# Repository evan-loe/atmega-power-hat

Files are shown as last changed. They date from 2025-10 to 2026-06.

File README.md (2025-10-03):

# ATMEGA Power Hat docs

## Introduction
The *ATMEGA Power Hat* is an RTC enabled Raspberry Pi compatible HAT *(Hardware-Attached-on-Top)* that can automatically wakeup and shutdown the pi on a given schedule.

## Setup Instructions

#### Run `configure_i2c_rtc.sh`
- Run [configure_i2c_rtc.sh](./configure_i2c_rtc.sh) with sudo. This script configures the RTC on the hat as a device recognizable by the Pi as a clock source by adding a dtoverlay. Now, the PI can keep its system time even if it powers off and does not get a chance to sync over NTP.

#### Flash the ATMEGA
- Use the provided .hex files under `build/` to flash the firmware onto the ATEMGA using your ISP and programs such as Microchip Studio or AVRDude. 
- FUSE BITS (Low High Ext): `E2 D9 FF`
- ATMEGA should come shipped with the correct High and Extended fuse bits. Change the low fuse bit to `0xE2` to enable internal clock running at 8 MHz

And thats it! Your hat should be ready to use

## Firmware Description
The source code of the firmware is available in `power.cpp`. It was developed using the Arduino v2.3.6 libararies.

The code does the following when powered ON:
- Sets up the ATMEGA as an I2C receiver on address `0x20`.
- Tells the power controller to send power to the PI by default
- Starts a watchdog that will restart the PIs power if it does not receive communication from the PI

While waiting for successful boot
- **It is the PI's responsibility to tell the ATMEGA of it's successful boot via the `Boot Success` I2C command

After receiving the `Boot Success` signal
- The ATMEGA waits for the `Shutdown` command

When the `Shutdown` command is received
- The ATMEGA waits n seconds as specified by the command. Then, it tells the power chip to cut power. It enters deep sleep mode until the RTC alarm wakes it. Upon awakening, it turns back on the power to the PI, waiting for the `Boot Success` command to be sent from the PI. 

The ATMEGA does not program the RTC over i2c.

## Supported I2C Transactions
The following section describes the transaction format recognized by the ATMEGA. The first byte denotes the command type, and the second byte denotes the value if applicable.

The Base Address of the ATMEGA is `0x20`

| Command | First Byte (txn_type) | Second Byte (data) | Description | Action |
|---|---|---|---|---|
| Shutdown | `0x00` | 0x00-0xFF | Shutdown command | Sets `shutdown_in` variable to data value |
| Boot Success | `0x01` | Any value | Boot success signal | Sets `successful_boot` flag to 1 |

#### Note on max number size
Since any data is encoded in a single byte, the max delay from receiving the i2c signal to cutting power is 2^8=256 seconds.

## Hardware
The CAD files can be found in the [ATMegaPowerCircuit](./ATMegaPowerCircuit/) folder.

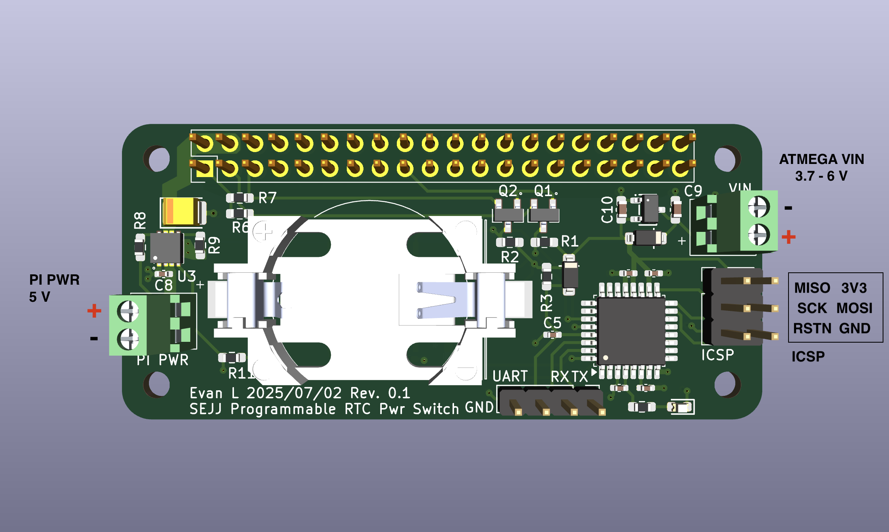
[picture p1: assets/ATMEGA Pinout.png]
ATMEGA Hardware Connections


## Compiling the firmwre
Select the Aruduino UNO as your device. Paste [power.cpp](./power.cpp) into your Arduino IDE and click `Sketch > Export Compiled Binary`

## Additional Reference Information
**RTC lib docs**: https://adafruit.github.io/RTClib/html/index.html (We are using the DS3231 RTC chip)

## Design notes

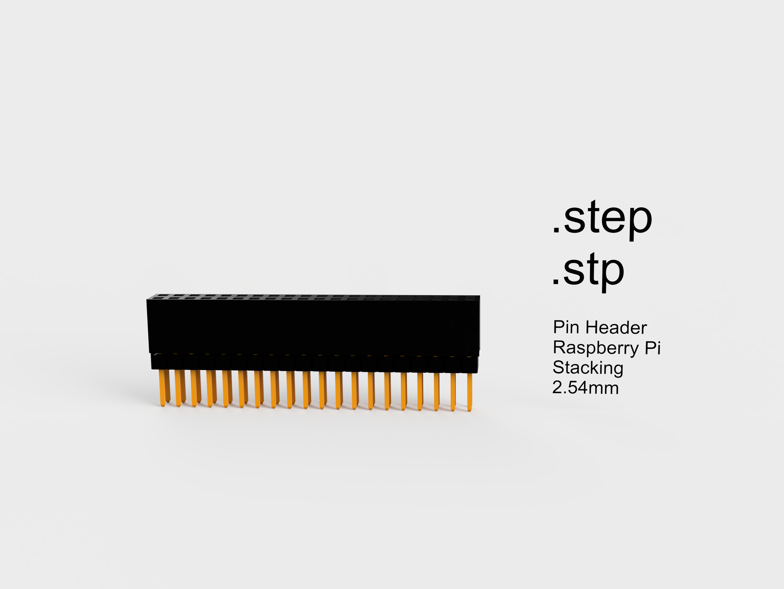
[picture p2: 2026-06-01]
ATMEGA Power Circuit/imported/pin-header-raspberrypi-stacking-2-54mm/Pin_Header-RaspberryPi - Stacking - 2.54mm.png

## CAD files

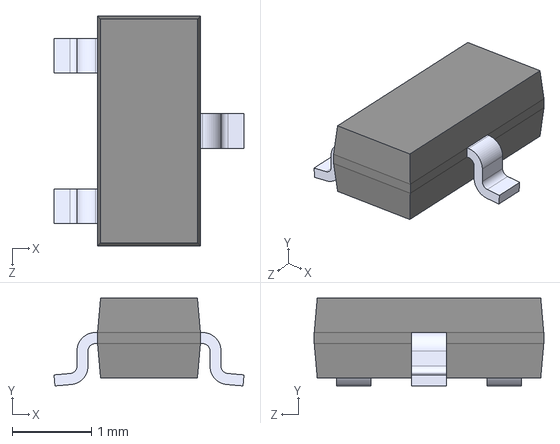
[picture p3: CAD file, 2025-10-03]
ATMEGA Power Circuit/imported/BSS138/BSS138.step
2.40 x 1.11 x 2.90 mm

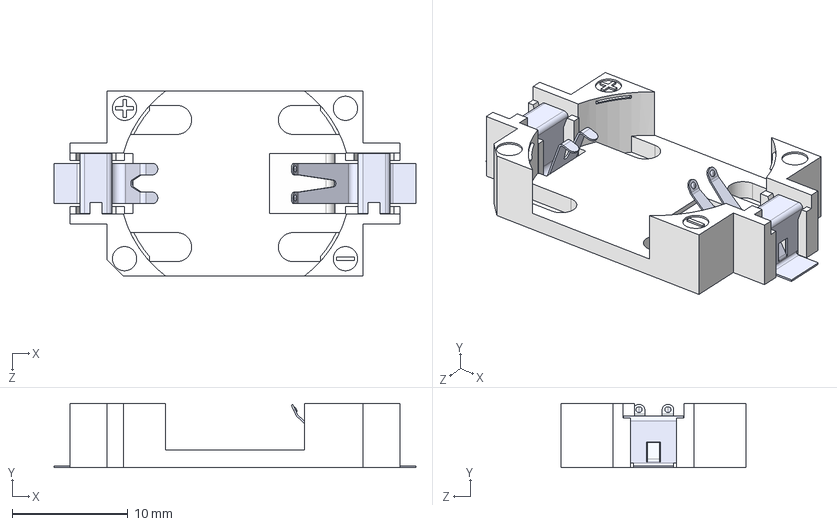
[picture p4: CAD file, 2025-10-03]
ATMEGA Power Circuit/imported/CR2032-BS-6-1/CR2032-BS-6-1--3DModel-STEP-56544.STEP
31.3 x 5.55 x 16.0 mm

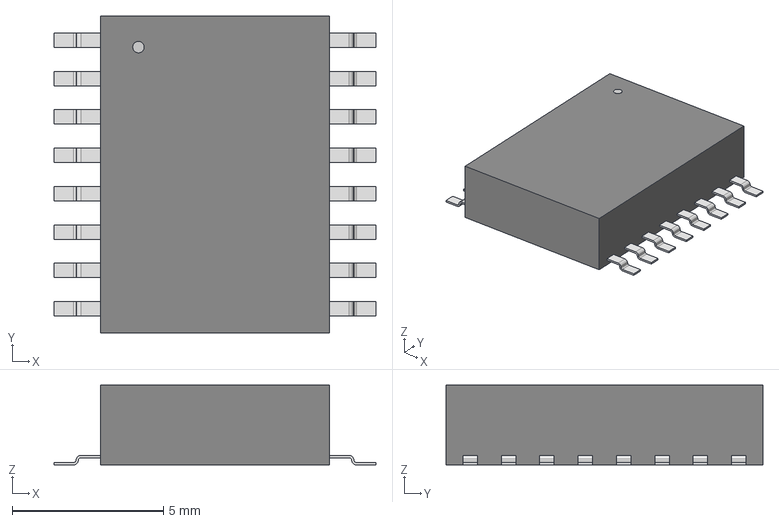
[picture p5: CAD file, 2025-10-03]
ATMEGA Power Circuit/imported/DS3231SN/21-0042B_16_MXM.step
10.6 x 10.5 x 2.64 mm

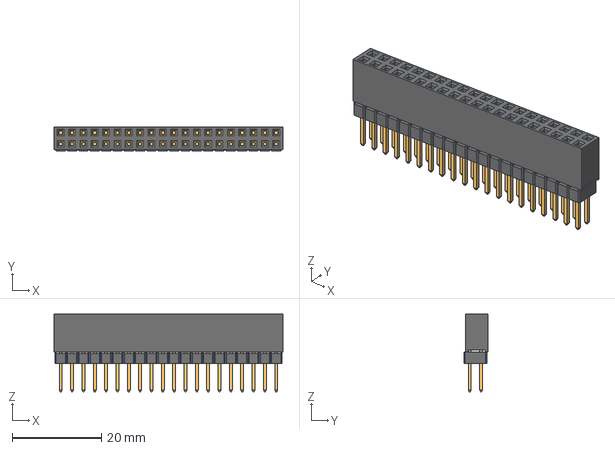
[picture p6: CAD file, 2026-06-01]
ATMEGA Power Circuit/imported/pin-header-raspberrypi-stacking-2-54mm/Pin Header - RaspberryPi - Stacking - 2.54mm_V2.step
51.3 x 5.33 x 17.4 mm

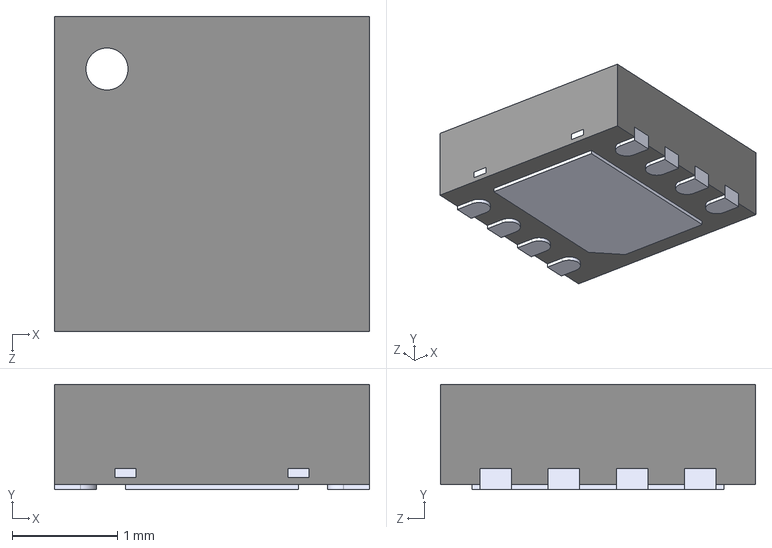
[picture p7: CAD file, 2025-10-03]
ATMEGA Power Circuit/imported/TPS2557DRBR/TPS2557DRBR.step
3.00 x 1.00 x 3.00 mm

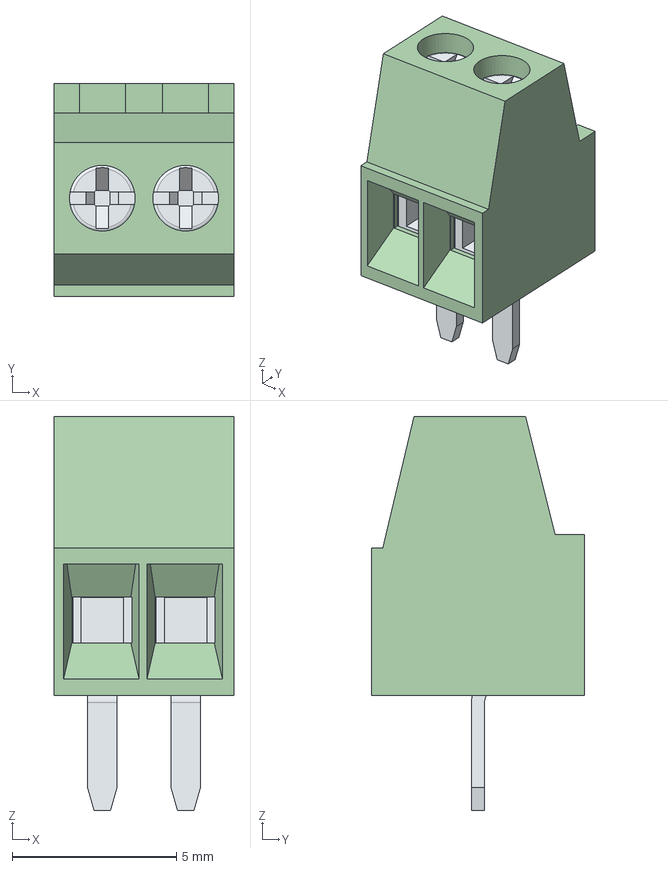
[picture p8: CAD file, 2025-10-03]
ATMEGA Power Circuit/imported/Weurth_Terminal_01x02_691210910002/691210910002.step
5.48 x 6.50 x 12.0 mm
6912109100xx_CAGE x 2
6912109100xx_PIN x 2
6912109100xx_VIS x 2

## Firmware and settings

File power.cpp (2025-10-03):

#include <Arduino.h>

#include <Wire.h>
#include <avr/sleep.h>
#include <avr/power.h>
#include <avr/interrupt.h>
#include <stdint.h>

// power_switch must be HIGH to send power to RPi
const int power_switch = 8;
const int alarm_int_pin = 2;

// the interrupt routine will set this to a positive value when we need to shutdown.
volatile int64_t shutdown_in = -1;
volatile int8_t successful_boot = 0;
int64_t loop_counter = 0;
unsigned char txn_type = 0;
int8_t bytes_recvd = 0;

#define RPI_ON HIGH
#define RPI_OFF LOW

void wakeUp();
void deep_sleep();
void receiveEvent(int howMany); // i2c receive howMany bytes

void wakeUp() {
  // Interrupt Service Routine (ISR)
  // Nothing is needed here, just wake up the microcontroller
}



void setup() {
  pinMode(power_switch, OUTPUT);
  digitalWrite(power_switch, RPI_ON);  // RPi should be on initially.

  pinMode(alarm_int_pin, INPUT_PULLUP);  // Set interrupt pin as input with internal pull-up resistor

  // Attach an interrupt to the pin
  attachInterrupt(digitalPinToInterrupt(alarm_int_pin), wakeUp, FALLING);

  // Initialize I2C communication as a slave with address 0x20
  Wire.begin(0x20);
  // Set up the function to handle incoming data
  Wire.onReceive(receiveEvent);

  Serial.begin(9600);  // For debugging
  Serial.println("\nI2C Receiver Ready. Waiting for signal from Pi to cut power...");
}

void loop() {

  if (successful_boot == 0 && loop_counter > 1200) {
    Serial.println("ERROR: No communication from PI so trying to resuscitate with a power cycle");
    digitalWrite(power_switch, RPI_OFF);
    delay(1000 * 20); // wait 20 seconds
    digitalWrite(power_switch, RPI_ON);
    loop_counter = 0;
    successful_boot = 0;
    shutdown_in = -1;
    Serial.println("Finished power cycle, waiting for communication from PI ...");
  } 
  else if(shutdown_in > 0)
  {
    Serial.print("ATMEGA will cut power to the RPi in ");
    Serial.print((long)shutdown_in);
    Serial.println(" seconds.");
    Serial.flush();
    delay(1000 * shutdown_in);
    shutdown_in = -1;
    digitalWrite(power_switch, RPI_OFF);

    Serial.println("ATMEGA entering sleep mode. Alarm will wake me up...");
    Serial.flush();

    deep_sleep();
    Serial.println("ATMEGA woke up. Turning PI on and waiting for signal to shutdown again...");
    Serial.flush();
    successful_boot = 0;
    loop_counter = 0;

    digitalWrite(power_switch, RPI_ON);
  }

  if (successful_boot != 1) {
    if (loop_counter % 5 == 0) {
      Serial.print("Looping count ");
      Serial.println((int) loop_counter, DEC);
    }
    loop_counter++;
  }
  delay(200);
}

void deep_sleep() {
  // Disable unnecessary peripherals to save power
  ADCSRA &= ~(1 << ADEN);  // Disable ADC
  power_adc_disable();     // Disable ADC
  power_spi_disable();     // Disable SPI
  power_twi_disable();     // Disable I2C
  power_timer0_disable();  // Disable timer 0
  power_timer1_disable();  // Disable timer 1
  power_timer2_disable();  // Disable timer 2


  // Prepare for sleep
  set_sleep_mode(SLEEP_MODE_PWR_DOWN);  // Set the sleep mode to the deepest power-down mode
  noInterrupts();                       // Disable interrupts while configuring sleep mode
  sleep_enable();                       // Enable sleep mode
  interrupts();                         // Re-enable interrupts

  sleep_cpu();  // Put the MCU to sleep. Execution halts here until an interrupt occurs.

  // Execution resumes here after waking up
  sleep_disable();  // Disable sleep mode

  // Re-enable peripherals after waking up
  power_adc_enable();     // enable ADC
  power_spi_enable();     // enable SPI
  power_twi_enable();     // enable I2C
  power_timer0_enable();  // enable timer 0
  power_timer1_enable();  // enable timer 1
  power_timer2_enable();  // enable timer 2
  ADCSRA |= (1 << ADEN);  // Re-enable ADC
}

// This function executes whenever i2c data is received from the master
void receiveEvent(int howMany) {
  // txn_types:
  // 0 - shutdown
  // 1 - successful boot
  while (Wire.available())
  {
    if (bytes_recvd == 0) 
    {
      txn_type = Wire.read();
      bytes_recvd++;
      Serial.println("Received first...");
      Serial.println(txn_type);
    } 
    else 
    {
      bytes_recvd = 0;
      unsigned char data = Wire.read();
      Serial.println("Received second...");
      Serial.println(data);

      if (txn_type == 0) {
        shutdown_in = (int) data;
      } 
      else if (txn_type == 1) 
      {
        successful_boot = 1;
      }
    }
  }
}
